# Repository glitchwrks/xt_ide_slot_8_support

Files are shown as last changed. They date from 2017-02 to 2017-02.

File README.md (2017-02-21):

# Slot 8 Support for the XT-IDE 8-Bit IDE Controller

[Glitch Works](http://www.glitchwrks.com/) daughterboard for Slot 8 Support on the XT-IDE. This module can be used with any XT-IDE that includes ISA pin `B8`, which is all [rev 3](http://www.glitchwrks.com/2016/07/06/xt-ide-rev3) boards, most rev 2 boards, and early rev 1 boards. Production rev 1 boards (2009-2010 era) had `B8` removed to reduce cost, and can't use this module

More info on the Glitch Works project to provide XT-IDE related boards, kits, and fully assembled units [can be found here](http://www.glitchwrks.com/xt-ide). A writeup on the Slot 8 Support design process [is available here](http://www.glitchwrks.com/2017/02/03/slot-8-support).

### Versions

Originally there were two sets of Gerber files for this project, one with silkscreen legends, and one where the legend was done as solder mask relief. I've since dropped the silkscreened version since the "nosilk" version can be run at any board house, even those with lousy silkscreen quality. Here's the current production board, with castellated mounting holes:

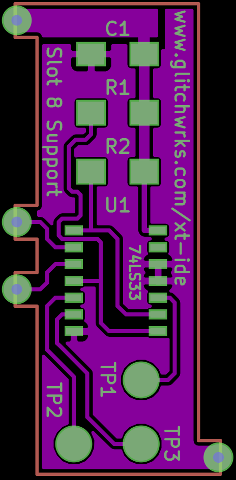
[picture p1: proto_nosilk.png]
Solder Mask Relief Version


This version is 100% functional and the Gerbers can be submitted directly to OSH Park. You'll receive a board with [castellated holes](http://docs.oshpark.com/tips+tricks/castellation/) (which may require some deburring). OSH Park boards have been run and tested, and found to be completely functional.

### Bill of Materials

You can find a BOM with Mouser part numbers [here](https://github.com/glitchwrks/xt_ide_slot_8_support/blob/master/bill_of_materials.md). Pull requests with BOMs for other suppliers are welcome! Do note that you can purchase complete parts kits from [The Glitch Works](http://www.glitchwrks.com/xt-ide) in addition to bare PC boards.

### Notes on Running This Board

This is a single-sided board, but most (all?) board houses that do prototype quantities will run it as a double-sided board with nothing on the solder side. As such, be aware that you *do* need to include the solder side solder mask file -- solder masks are negative, so omitting the solder mask file when submitting to e.g. [OSH Park](https://oshpark.com) will result in a solid solder side mask, which will get in the through-holes and make assembly more difficult!

The design files for this board now specify [castellated holes](http://docs.oshpark.com/tips+tricks/castellation/) for the mounting tabs. Not all board houses can do this -- OSH Park can, and you can submit the Gerber ZIP directly to them and get a functional board.

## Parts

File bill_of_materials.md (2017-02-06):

Slot 8 Support Bill of Materials
--------------------------------

Below is the Bill of Materials for the Slot 8 Support board:

```
Ref(s)      Value                               Mouser P/N
-------------------------------------------------------------------------------
U1          74LS33                              595-SN74LS33DR
R1, R2      10K 1206 SMD resistor               588-AS12J1002ET
C1          0.1uF 50V 1206 SMD MLC capacitor    80-C1206104K5RAC7867            
```

Parts Kits
----------

Parts kits including the PC board are available from [The Glitch Works](http://www.glitchwrks.com/xt-ide) for $5 USD + shipping. Some substitutions will be made for the above list. The kit is a complete parts kit and includes everything you need to build a Slot 8 Support -- you supply the solder and tools.

Substitutions
-------------

All resistors and capacitors are 1206 body SMD components. U1 is SOIC.

R1, R2 are pull-up resistors, their values are noncritical. Anything from 2.2K - 47K should be fine.
C1 is power supply bypass, 0.01 - 0.1 uF is fine.

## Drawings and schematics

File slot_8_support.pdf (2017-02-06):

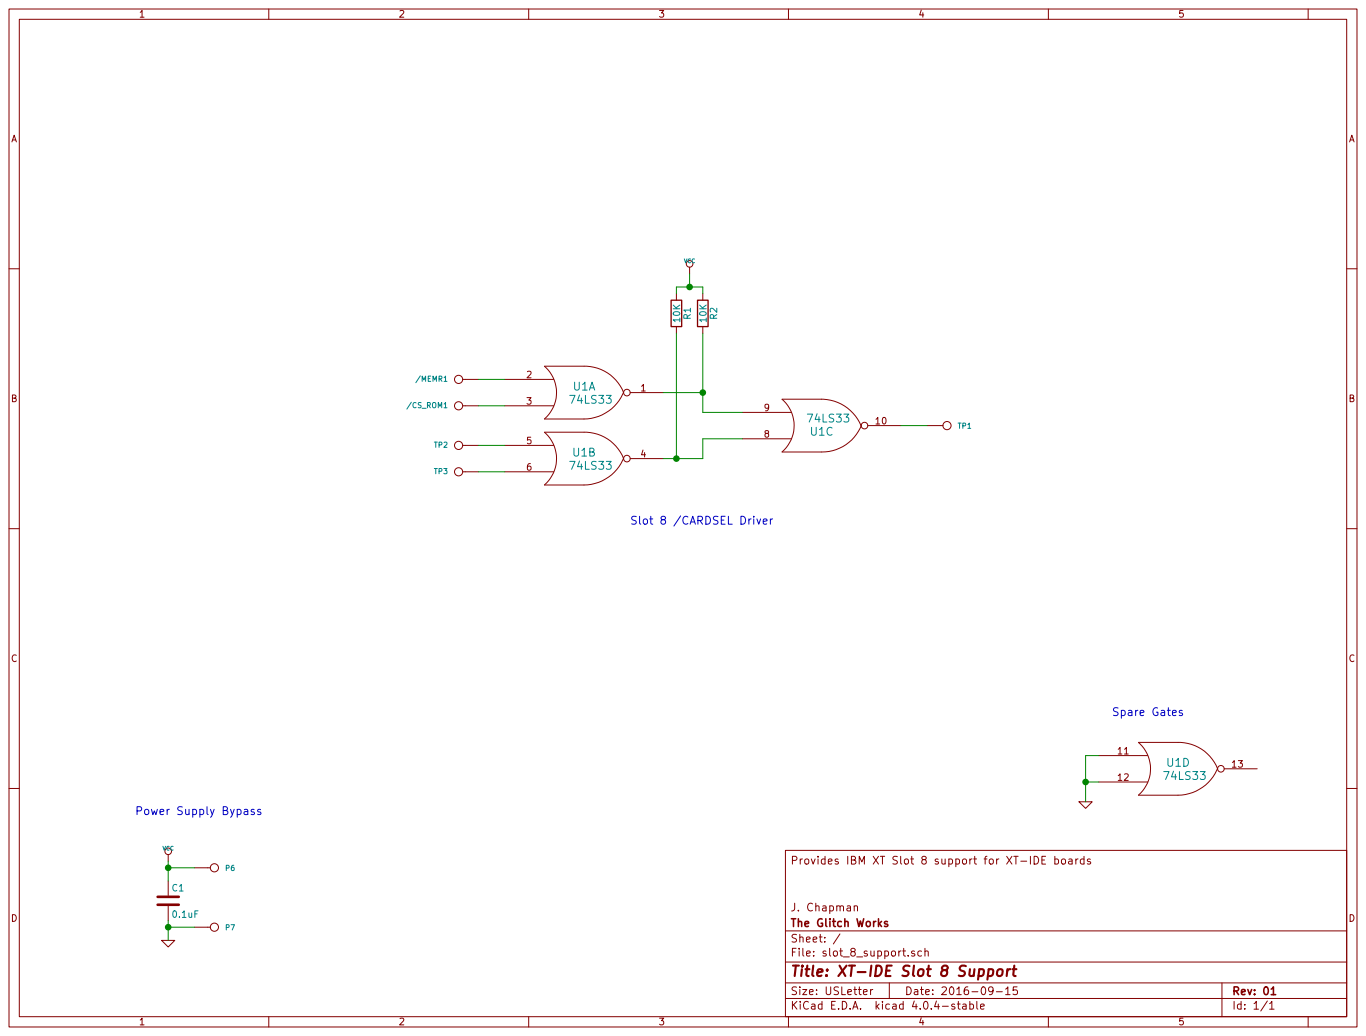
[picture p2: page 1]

Provides IBM XT Slot 8 support for XT-IDE boards

J. Chapman
File: slot_8_support.sch Sheet: / The Glitch Works

Id: 1/1 Title: XT-IDE Slot 8 Support

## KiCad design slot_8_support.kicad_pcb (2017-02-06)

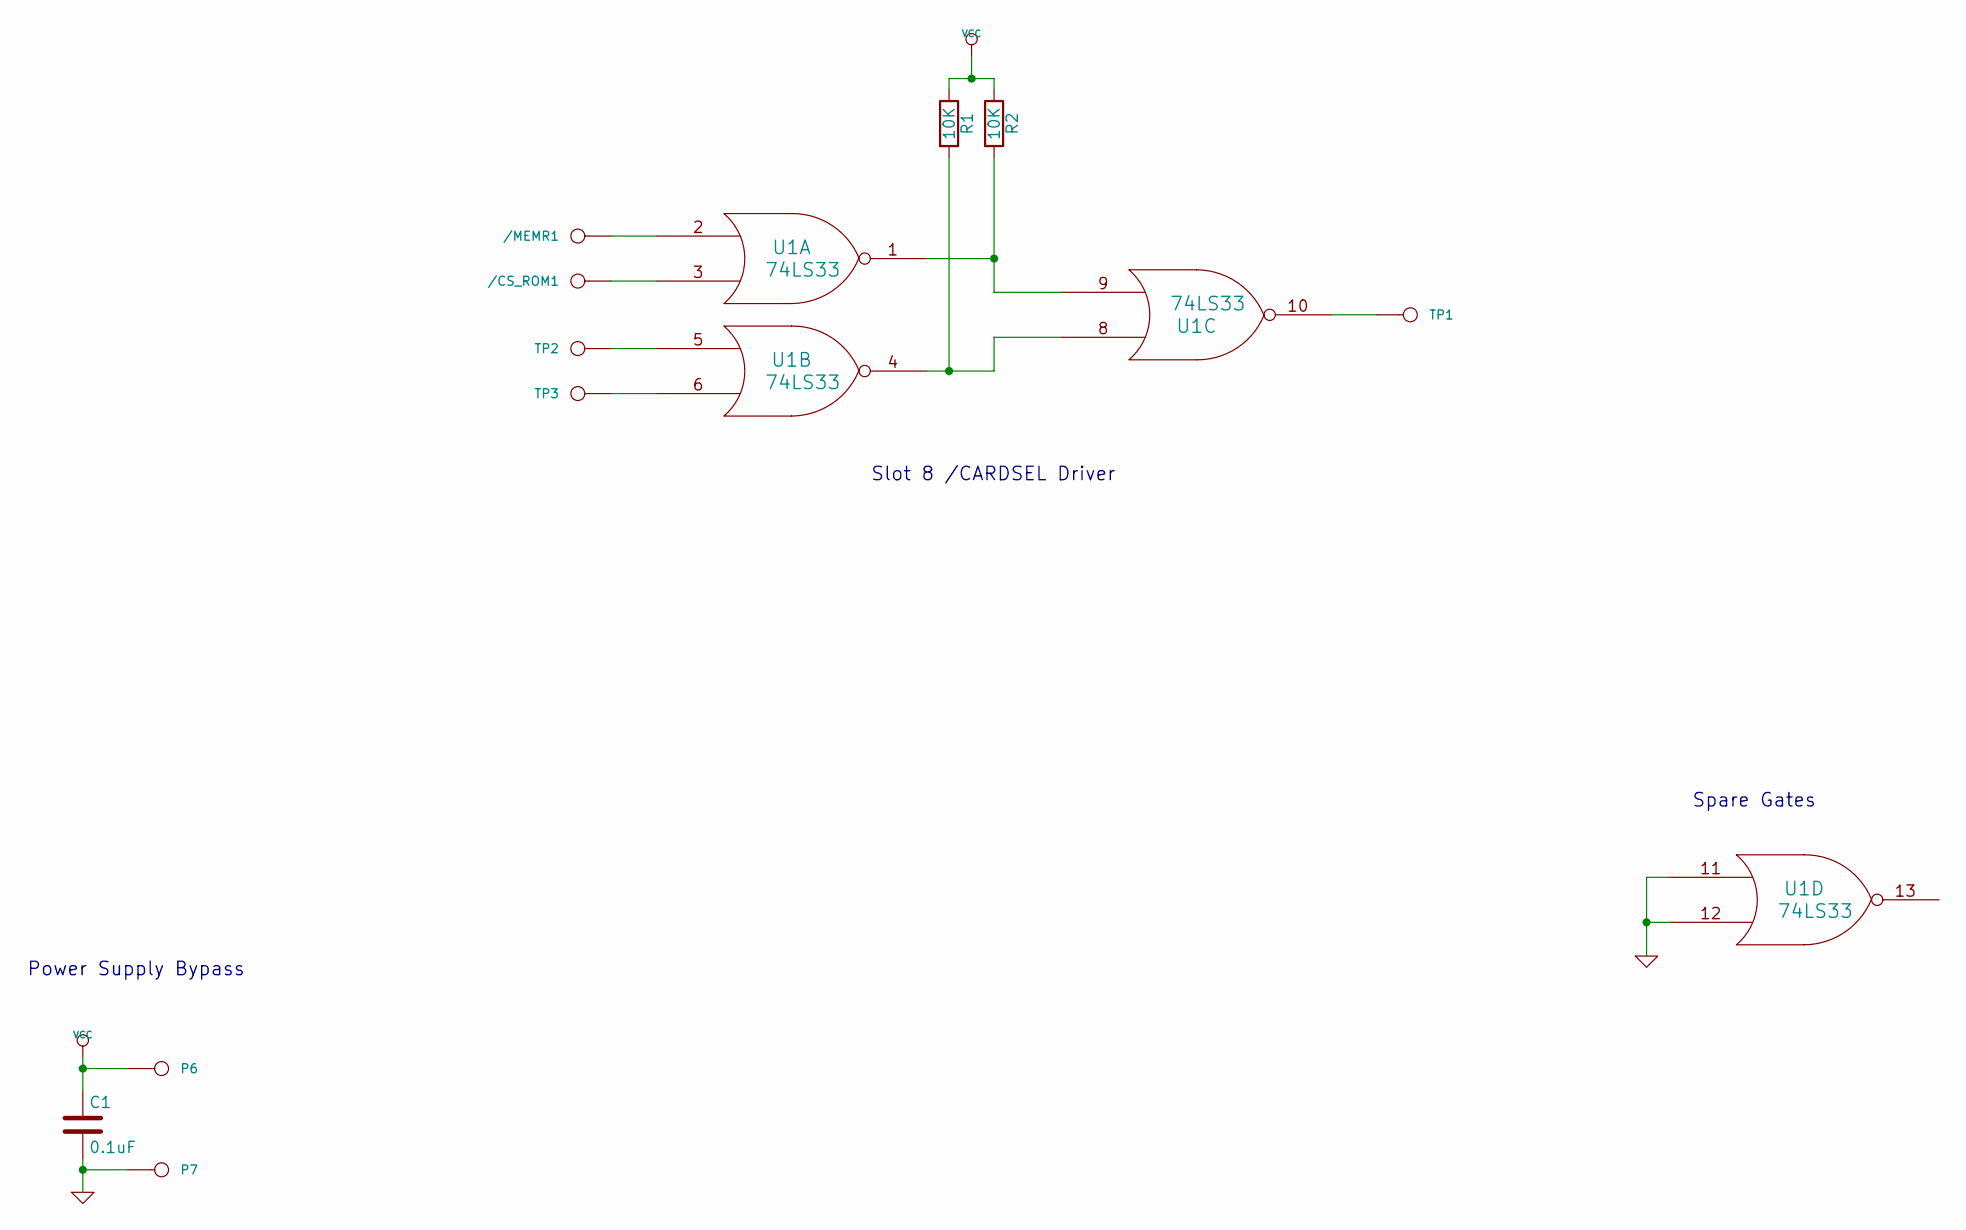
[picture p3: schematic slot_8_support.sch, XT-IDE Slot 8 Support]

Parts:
/CS_ROM1: CONN_1; SolderWirePad_single_0-8mmDrill
/MEMR1: CONN_1; SolderWirePad_single_0-8mmDrill
C1: 0.1uF; C_1206_HandSoldering
P6, P7: CONN_1; SolderWirePad_single_0-8mmDrill
R1, R2: 10K; R_1206_HandSoldering
TP1, TP2, TP3: CONN_1; SMD_TESTPOINT
U1: 74LS33; SOIC-14_N

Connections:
GND: C1.2, P7.1, U1.7 (GND), U1.11, U1.12
unnamed: /CS_ROM1.1, U1.3
unnamed: /MEMR1.1, U1.2
unnamed: R1.2, U1.4, U1.8
unnamed: R2.2, U1.1, U1.9
unnamed: TP1.1, U1.10
unnamed: TP2.1, U1.5
unnamed: TP3.1, U1.6
VCC: C1.1, P6.1, R1.1, R2.1, U1.14 (VCC)

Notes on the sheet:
Slot 8 /CARDSEL Driver
Power Supply Bypass
Spare Gates

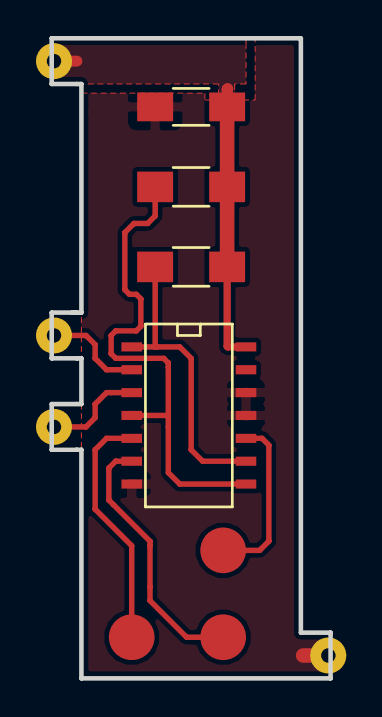
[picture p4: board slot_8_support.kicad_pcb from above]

Board: 2 copper layers, 15.5 x 35.6 mm, 11 parts (0 on the bottom side), 9 nets.

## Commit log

2017-02-06 Removing dup Excellon drill file
    [slot_8_support.drl]
2017-02-06 Adding Mouser BOM
2017-02-06 Splitting silkscreen/nosilk boards, adding copper pour for mask relief, bottom mask layer
    [slot_8_support-B.Cu.gbr, slot_8_support-B.Mask.gbr, slot_8_support-B.SilkS.gbr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]
2017-02-06 Adding castellated mounting holes for nosilk version
    [slot_8_support_nosilk.kicad_pcb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]
2017-02-21 Updating project for successful castellated hole run, removing silkscreen version
    [slot_8_support.kicad_pcb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]
2017-02-21 Adding new Gerber rendering
